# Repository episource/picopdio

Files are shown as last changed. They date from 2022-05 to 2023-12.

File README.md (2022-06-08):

# About
Another internet radio player project reusing parts and case of an old DNT IPdio Tune internet radio, that stopped working due to the shutdown of Reciva services.

The project is build using PlatformIO and [arduino-pico](https://github.com/earlephilhower/arduino-pico) core around a [Raspberry Pi Pico](https://www.raspberrypi.com/products/raspberry-pi-pico/) microcontroller. It uses nodejs' [llhttp](https://github.com/nodejs/llhttp) parser for reading icecast radio streams.

Configuration is stored on an SD card placed into the radio's front panel SD card slot.

# Parts
This is the list of parts used in the project. See the [schematics](schematics/picopdio.pdf) for details.

 * DNT IPdio Tune
    - Case
    - Mother board including Wolfson WM8711B audio codec/DAC and power supply
    - Front Panel including some unknown Tinsharp 132x48 LCD (ST7565 compatible)
 * [Raspberry Pi Pico](https://www.raspberrypi.com/products/raspberry-pi-pico/)
 * [Adafruit VS1053B Breakout](https://learn.adafruit.com/adafruit-vs1053-mp3-aac-ogg-midi-wav-play-and-record-codec-tutorial/downloads-and-links)
 * [Microchip MCP23017 IO Expander](https://www.microchip.com/en-us/product/mcp23017)
 * [Sparkfun SX1509 IO Expander](https://www.sparkfun.com/products/13601)
 * [WIZnet W850io SPI ethernet shield](https://www.wiznet.io/product-item/wiz850io/) ~~WIZnet W5500 based no-name `W5500 Lite` SPI ethernet adapter~~ 
   - no-name W850io clones had auto negotiation issues with some switches 
   - therefore replaced by WIZnet made W850io shield
   - note: disabling auto negotiation and forcing 100MBit or 10MBit Half Duplex instead solved these issues with the no-name clones as well
   - see also WIZnet forums for a [similar issue](https://forum.wiznet.io/t/topic/5529)
 * [Pololu Mini Pushbutton Power Switch #2808](https://www.pololu.com/product/2808)

# Further Reading
Below some links with background information on reciva based internet radios
 * [Sharpfin Webpage](https://www.sharpfin.org/)
 * [Sharpfin Repo](https://github.com/philsmd/sharpfin)
 * [Reciva Barracuda Radio Module Datasheet](https://elinux.org/images/5/5f/Barracuda_1.6.pdf)

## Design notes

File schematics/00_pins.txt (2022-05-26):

              G                 G 
  / 20 18 16 14 12 10 08 06 04 02 | J1
  | 19 17 15 13 11 09 07 05 03 01 |             J2/U11
       V3        G             V3               ------
     J3                                         02  01
     -----                                      04  03
     02 01 G                                    06  05
     04 03                                      08  07
     06 05                                      10  09 G
   G 08 07                                      12  11
     10 09                                   V3 14  13
     12 11                                    G 16  15
     14 13                                      18  17
     16 15                                      20  19
     18 17                                    G 22  21
     20 19  G                                   24  23 G
  NC 22 21 NC                                   26  25
  NC 24 23 NC                                 G 28  27
  NC 26 25 NC                                   30  29
  NC 28 27 NC                                   32  31 G
  NC 30 29 NC                                V3 34  33
  NC 32 31 NC                              V1.8 36  35
                                                38  37
                                              G 40  39

  / 01 02 03 04 05 06 07 08 09 10 11 12 13 14 15 16 |J7
  | 17 18 19 20 21 22 23 24 25 26 27 28 29 30 31 32 |

J1:
03 = SDDAT3 (CS) via J11/7 zu SD/10
05 = SDDAT2 via J11/8 zu SD/11
06 = WM8711B DACDAT (I2S DAT)
07 = SDDAT1 via J11/ zu SD/2
08 = WM8711B BCLK (I2S BCLK)
09 = SDDAT0 (MISO) via J11/ zu SD/3
10 = WM8711B DACLRC (I2S LRCLK)
13 = SDCMD (MOSI) via J11/6 zu SD/11
15 = SDCLK via Koaxkabel zu SD/05
16 = LCD Backlight FET via R60
19 = I2C SCL

J2:
01 = Power LED FET via R133
08 = I2C SDA
10 = SD Card Detect (SD/8) via J11/1
12 = SD Write Protect (SD/1) via J11/2
15 = Taster Drehknopf B | Taster Power Back
17 = Taster Pre/Play B | Taster Mode B | Taster Back B
19 = Drehgeber B
21 = Drehgeber A
33 = Drehknopf LED FET via R132

J3:
02 = Taster Drehknopf A | Taster Back A
04 = Taster Mode A | Taster Power A
06 = Taster Pre/Play A
----
03 = LCDD7
05 = LCDD6
07 = LCDD5
09 = LCDD4
11 = LCDD3
13 = LCDD2
15 = LCDD1
17 = LCDD0
----
10 = LCDN5/C5
12 = LCDN4/C4
14 = LCDN3/C3
16 = LCDN2/C2
18 = LCDN1/C1
20 = LCDN0/C0

Taster/Drehgeber: A = oben; B = unten

J7 -> Sockel/Pin = Beschreibung
1  -> J2/15      = Taster Drehknopf B | Taster Power B
3  -> J2/01      = Power LED FET via R133
4  -> J1/16      = LCD Backlight FET via R60 (Pulldown zu GND via R61)                                                                            
5                = GND
14  -> J2/17     = Taster Pre/Play B | Taster Mode B | Taster Back B
15  -> J2/19     = Drehgeber B
16               = GND
17  -> J3/04     = Taster Mode A | Taster Power A
20  -> J2/33     = Drehknopf LED FET via R132
21               = +5V
22               = +3V3?
29  -> J3/06     = Taster Pre/Play A
30  -> J3/02     = Taster Drehknopf A | Taster Back A
32  -> J2/21     = Drehgeber A

Drehgeber Mitte = GND, A/B per Kondensator zu Ground entprellt

Button-Matrix:

      | J3/02     | J3/04 | J3/06   
J2/15 | Drehknopf | Power | 
J2/17 | Back      | Mode  | Pre/Play

Notizen SD Card Socket

|  11 10 09 08 07 06 05 04 03 02 01
\___________________________________|

01 = Verbunden mit P07/P04 (GND) wenn Karte ohne Write Protect gesteckt oder keine Karte, high wenn WP -> J2/12
02 = SDDAT1 -> J1/7
03 = SDDAT0 -> J1/9
04 = GND
05 = SDCLK -> via Koaxkabel zu J1/15
06 = V3 (Kondensator zu GND)
07 = GND
08 = SD Card Detect (GND wenn Karte gesteckt) -> J2/10
09 = SDCMD -> J1/13
10 = SDDAT3 -> J1/3
11 = SDDAT2 -> J1/5

J11
|----|
| 01 | SD Card Detect (SD/08) -> J2/10
| 02 | SD Write Protect (SD/01) -> J2/12
| 03 | SDDAT1 -> J1/7
| 04 | SDDAT0 (MISO) -> J1/9
| 05 | seitlicher Pin SD Card Socket. Bedeutung unklar. Kondensator zu GND.
| 06 | SDCMD (MOSI) -> J1/13
| 07 | SDDAT3 (CS) -> J1/3
| 08 | SDDAT2 -> J1/5
| 09 | V3
| 10 | GND
|----|

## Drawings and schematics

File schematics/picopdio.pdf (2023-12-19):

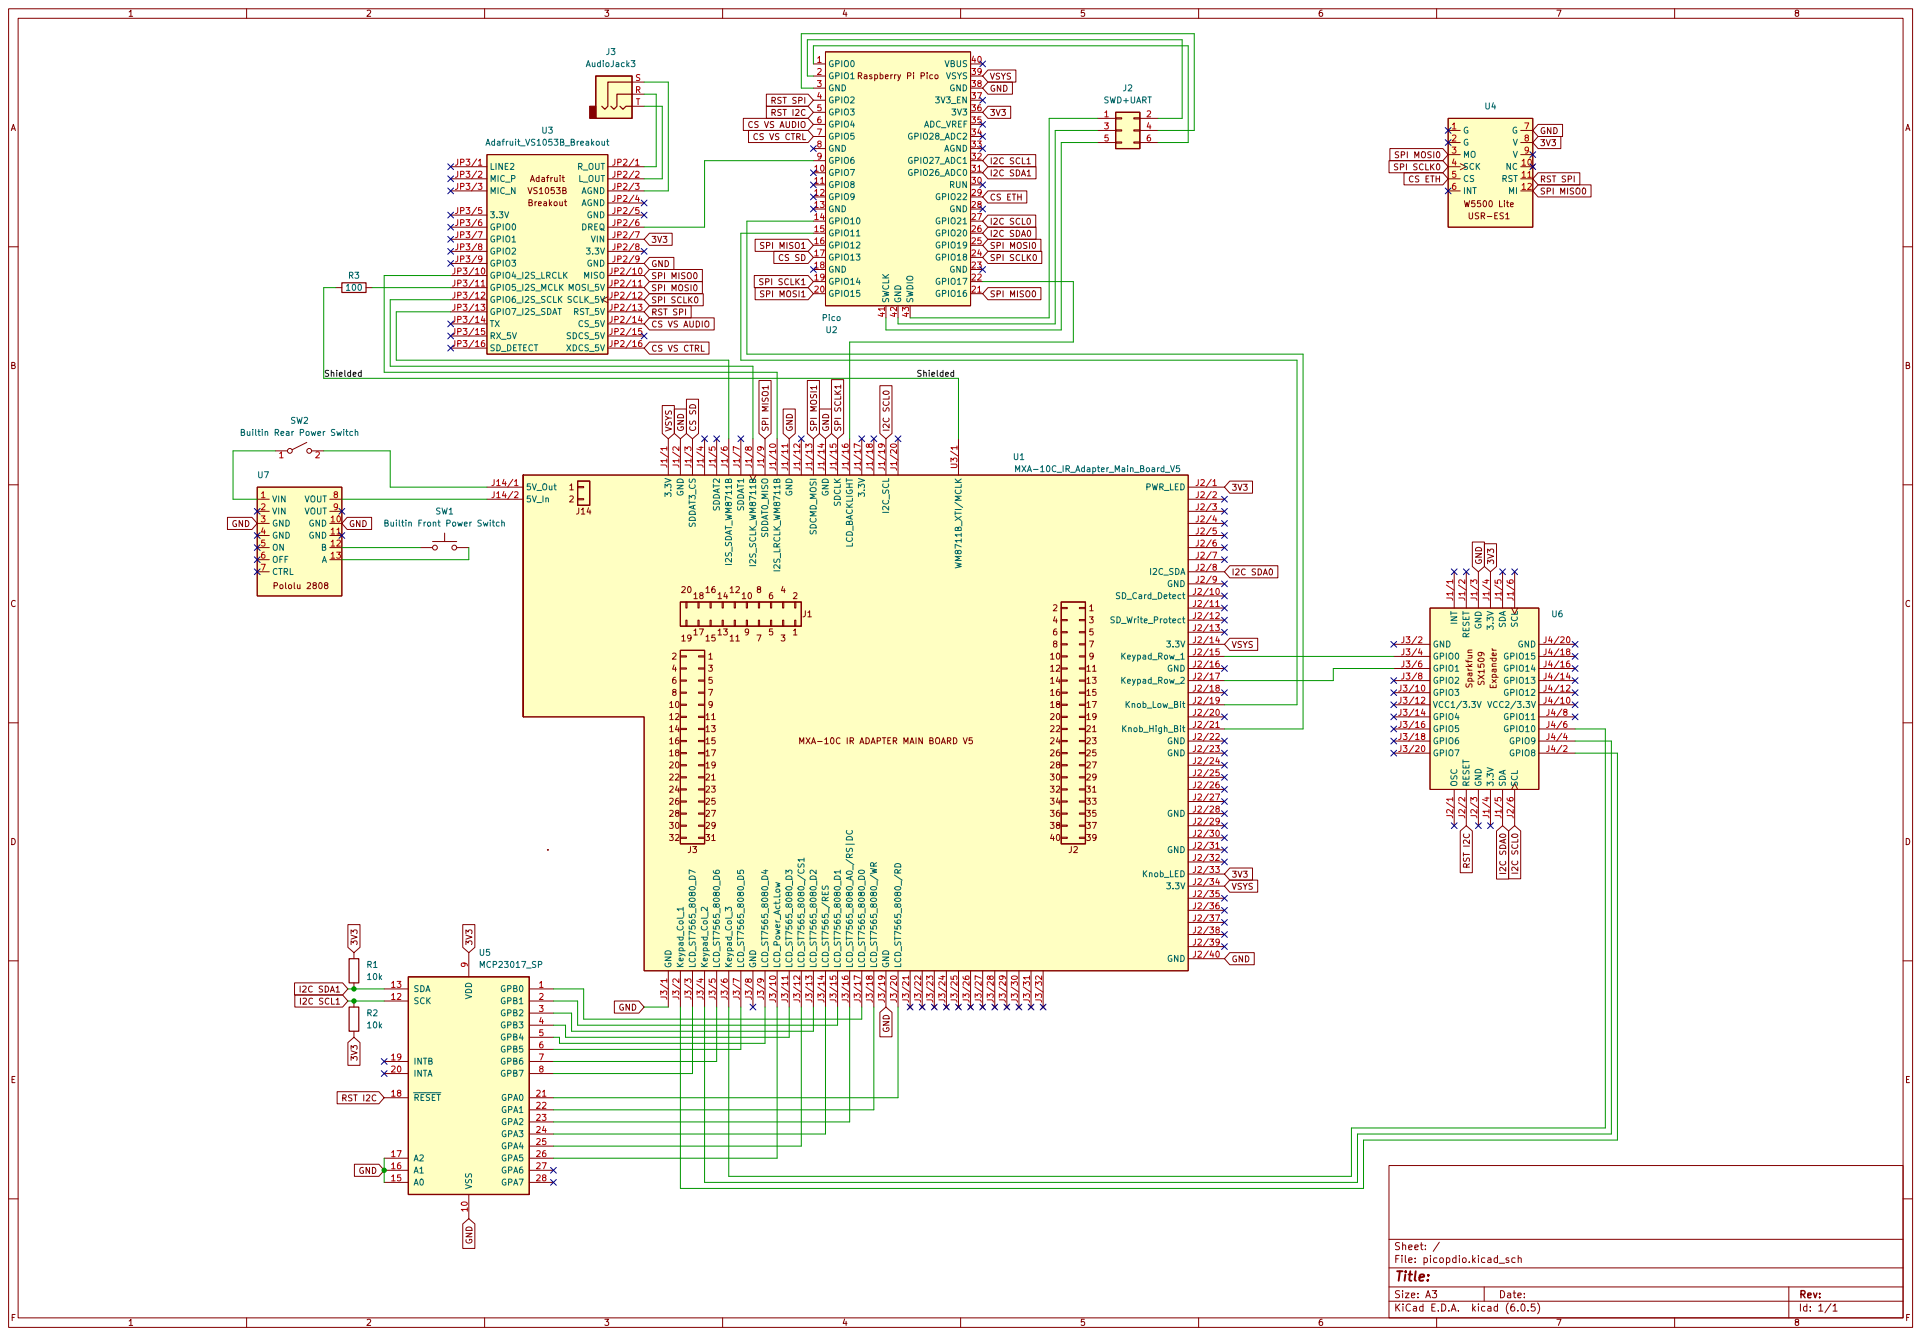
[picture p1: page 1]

SPI SCLK0 RST SPI GND GND

CS VS CTRL RST I2C

SPI SCLK1 SPI MISO1 CS SD

CS VS CTRL CS VS AUDIO

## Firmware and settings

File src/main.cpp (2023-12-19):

#include <Arduino.h>
#include <Ethernet3.h>
#include <pico.h>
#include <SdFat.h>
#include <SPI.h>
#include <Wire.h>

#include <RPi_Pico_TimerInterrupt.h>
#include <SparkFunSX1509.h>
#include <VS1053.h>

#include <hardware/watchdog.h>

#include "PicopdioDefinitions.h"

#include "PicopdioConfig.h"
#include "UserInterface.h"
#include "RotaryDecoder.h"
#include "IcyStreamClient.h"
#include "WM8711.h"


RPI_PICO_Timer khzHeartbeatTimer(0);
PicopdioConfig<10, 1000> picopdioConfig;
UserInterface ui(0x20, WIRE_HIGH_SPEED, 1, 1, 0, 4, 2, 3, 5);
RotaryDecoder rotdec;
EthernetClient ethClient;
VS1053 player(VS1053_CS, VS1053_DCS, VS1053_DREQ);
WM8711 dac(WIRE_LOW_SPEED, 0x1b);

// global variable required by IniFile library
SdFat SD;

// best buffer size: 8k - 32k
// feedLimit = 32000: EthernetClient shows nondeterministic behavior for larger sizes
IcyStreamClient<16000, 4096, 32000, false> icyStream(ethClient);

volatile uint8_t wantedStationIdx = 0;
critical_section_t wantedStationUpdateSection;

volatile bool core0SetupDone = false;
volatile bool playing = true;


SX1509 sx1509;

#define KEY_ROWS 2
#define KEY_COLS 3
#define KEY_UNUSED 0xff
#define KEY_DIM 0xfe
uint8_t keyMap[KEY_ROWS][KEY_COLS] = {
        {KEY_DIM, KEY_UNUSED, KEY_UNUSED},
        {2, 1, 0}
};

void setupOutLine(pin_size_t pin, PinStatus init);
void setupCsLine(pin_size_t pin);
void reboot();
void showHttpError(int statusCode);
void showNoLinkError();

uint8_t loadStation() {
    File32 stationFile = SD.open(STATION_FILE, FILE_READ);
    uint8_t result = stationFile.available() ? (uint8_t) stationFile.read() : 0;
    stationFile.close();

    if (result < 0) {
        return 0;
    } else if (result >= picopdioConfig.numStations()) {
        return picopdioConfig.numStations() - 1;
    }

    return result;
}

void storeStation(const uint8_t stationIdx) {
    const uint8_t curStationIdx = loadStation();
    if (stationIdx == curStationIdx) {
        DEBUGV("station file already up-to-date: %d - skipping write!\n", stationIdx);
        return;
    }

    File32 stationFile = SD.open(STATION_FILE, FILE_WRITE);
    stationFile.seek(0);
    stationFile.write(stationIdx);
    stationFile.close();

    DEBUGV("station file written: %d!\n", stationIdx);
}

bool khzHeartbeat(struct repeating_timer *t) {
    RotaryDecoder::Step step = rotdec.readAndDecode(CHANNEL_SELECTOR_ROT_HIGH, CHANNEL_SELECTOR_ROT_LOW);
    if (step == RotaryDecoder::NO_STEP) {
        return true;
    }

    critical_section_enter_blocking(&wantedStationUpdateSection);

    uint8_t maxStationIdx = picopdioConfig.numStations() - 1;
    if (step == RotaryDecoder::BACKWARD && wantedStationIdx == 0) {
        wantedStationIdx = maxStationIdx;
    } else if (step == RotaryDecoder::FORWARD && wantedStationIdx == maxStationIdx) {
        wantedStationIdx = 0;
    } else {
        wantedStationIdx += step;
    }

    critical_section_exit(&wantedStationUpdateSection);

    return true;
}

void setup() {
    critical_section_init(&wantedStationUpdateSection);

    //Serial.begin(115200);
    Serial1.begin(115200);

    SPI_MAIN.begin(false);
    SPI_DEDICATED_SD.begin(false);

    while (true) {
        DEBUGV("Initializing...\n");

        setupCsLine(ETH_CS);
        setupCsLine(SD_CS);
        setupCsLine(VS1053_CS);
        setupCsLine(VS1053_DCS);

        // configure reset line (no reset)
        delay(DEFAULT_INIT_DELAY_MS);
        setupOutLine(SPI_COMPONENTS_RESET_LOW, HIGH);

        if (!SD.begin(SdSpiConfig(SD_CS, DEDICATED_SPI, SPI_DEDICATED_SD_SPEED, &SPI_DEDICATED_SD))) {
            DEBUGV("Failed to init SD\n");
            continue;
        }

        if (!picopdioConfig.init(CONFIG_FILE)) {
            DEBUGV("Failed to read configuration from SD card!\n");
            continue;
        }

        if (picopdioConfig.numStations() == 0) {
            DEBUGV("No stations found!\n");
            continue;
        }

        // no need to enter critical section here:
        // parallelism starts when core0 is ready
        wantedStationIdx = loadStation();


        // Reset other spi slaves
        digitalWrite(SPI_COMPONENTS_RESET_LOW, LOW);
        delay(DEFAULT_INIT_DELAY_MS);
        digitalWrite(SPI_COMPONENTS_RESET_LOW, HIGH);

        delay(DEFAULT_INIT_DELAY_MS);
        Ethernet.setCsPin(ETH_CS);
        Ethernet.init(2);
        Ethernet.begin(
                const_cast<uint8_t *>(picopdioConfig.getMac()),
                picopdioConfig.getIp(), picopdioConfig.getDns(), picopdioConfig.getGateway());

        switch (picopdioConfig.compatMode()) {
            case ETH_FULL_AUTONEG:
                Ethernet.phyMode(ALL_AUTONEG);
                break;
            case ETH_100_HD:
                Ethernet.phyMode(HALF_DUPLEX_100);
                break;
            case ETH_10_HD:
                Ethernet.phyMode(HALF_DUPLEX_10);
                break;
            case ETH_HW_DEFAULT:
            default:
                // nothing to do
                break;
        }


        player.begin();

        // 4 == VS1053;
        if (player.getChipVersion() != 4) {
            DEBUGV("Unknown VLSI chip %d\n");
            continue;
        }
        player.loadDefaultVs1053Patches();

        //player.switchToMp3Mode(); // optional, some boards require this
        player.setVolume(0);
        player.enableI2sOut();

        break;
    }

    icyStream.setOnIcyMetadataChanged([]() -> void {
        if (playing) {
            ui.setTitle(icyStream.icyTitle());
        }
    });

    core0SetupDone = true;
}

void loop() {
    static uint8_t connectedStationIdx = UINT8_MAX;
    static int minBuffer = 100;
    static uint8_t bufLevel = 4;
    static uint32_t lastBufLevelUpdateMillis = 0;
    static bool lastLinkState = true;

    uint8_t requestedStationIdx = wantedStationIdx;
    uint32_t nowMs = millis();
    boolean stationChangeRequested = requestedStationIdx != connectedStationIdx;

    if (!icyStream.connected() || (bool)Ethernet.link() != lastLinkState || stationChangeRequested) {
        if (playing) {
            player.setVolume(0);
            player.stopSong();

            playing = false;
        }

        if (!Ethernet.link()) {
            if (lastLinkState) {
                icyStream.stop();
                showNoLinkError();
            }

            lastLinkState = false;
            return;
        }

        if (stationChangeRequested || !lastLinkState) {
            DEBUGV("Link ready - PHY state: 0x%02x\n", Ethernet.phyState());

            ui.showLoadScreen();

            icyStream.connect(picopdioConfig.getStationUrl(requestedStationIdx));
            connectedStationIdx = requestedStationIdx;

            lastLinkState = true;
        } else {
            return;
        }
    } else if (nowMs - lastBufLevelUpdateMillis > 1000) {
        lastBufLevelUpdateMillis = nowMs;

        if (minBuffer > 80 || icyStream.bufferFull()) {
            bufLevel = 4;
        } else if (minBuffer > 55) {
            bufLevel = 3;
        } else if (minBuffer > 30) {
            bufLevel = 2;
        } else if (minBuffer > 5) {
            bufLevel = 1;
        } else {
            bufLevel = 0;
        }

        minBuffer = 100;
        ui.setBufferLevel(bufLevel);
    }

    const int read = icyStream.feedBuffer();
    if (read < 0) {
        showHttpError(icyStream.httpStatus());
        icyStream.stop();
    }

    minBuffer = std::min(minBuffer, icyStream.bufferFillPercent());

    if (!playing) {
        if (!icyStream.bufferFull()) {
            return;
        }

        player.startSong();
        player.setVolume(VOLUME);
        playing = true;

        lastBufLevelUpdateMillis = nowMs;
        minBuffer = 100;
        bufLevel = 4;

        ui.showTitleScreen(icyStream.icyTitle(), 4);
        storeStation(connectedStationIdx);
    }

    icyStream.readTo([](const uint8_t *data, int size) -> int {
        return player.playNonBlocking(data, size);
    });
}

void setup1() {
    // activate LCD backlight as early as possible to provide user feedback
    pinMode(LCD_BG, ANALOG_OUTPUT);
    analogWrite(LCD_BG, LCD_DEFAULT_BRIGHTNESS);

    // reset I2C slaves
    setupOutLine(I2C_COMPONENTS_RESET_LOW, LOW);
    delay(DEFAULT_INIT_DELAY_MS);
    digitalWrite(I2C_COMPONENTS_RESET_LOW, HIGH);

    pinMode(CHANNEL_SELECTOR_ROT_HIGH, INPUT_PULLUP);
    pinMode(CHANNEL_SELECTOR_ROT_LOW, INPUT_PULLUP);

    WIRE_LOW_SPEED.setSCL(WIRE_LOW_SPEED_SCL);
    WIRE_LOW_SPEED.setSDA(WIRE_LOW_SPEED_SDA);
    WIRE_LOW_SPEED.setClock(400000);
    WIRE_LOW_SPEED.begin();

    WIRE_HIGH_SPEED.setSCL(WIRE_HIGH_SPEED_SCL);
    WIRE_HIGH_SPEED.setSDA(WIRE_HIGH_SPEED_SDA);
    // rp2040 is specified to support Fast Mode+ (up to 1MHz Baud Rate)
    // it has 80k builtin internal pull-ups
    // MCP23017 is specified to support baud rate up to 1.7MHz
    // - using external pull-ups rp2040 can do more than 1MHz, though
    // - using external 10k pull-ups, 1.35MHz baud rate seem to work most
    //   of the time, up to 1.30MHZ stable,
    // - using lower pull-ups does not help to achieve higher rate
    // - note though, that going >1MHZ makes the bus very sensitive to noise
    //   on breadboard designs
    WIRE_HIGH_SPEED.setClock(1300000);
    WIRE_HIGH_SPEED.begin();

    // early display of gui!
    ui.begin(true);
    if (ui.resetRequest()) {
        DEBUGV("Failed to initialize display. Rebooting...\n");
        reboot();
    }

    // start dac + shaft and key decoding only after core 0 is ready
    // => stations not available before SD card has been read
    // => MCLK not ready
    while (!core0SetupDone) {
        yield();
    }

    // wait for core0 for MCLK to be ready
    dac.begin();

    // wait for core0 to finish reading PicopdioConfig
    khzHeartbeatTimer.attachInterrupt(1000, khzHeartbeat);

    sx1509.begin(0x3E, WIRE_LOW_SPEED);
    sx1509.reset(false);

    // normal buttons: debounce time 4ms is good
    // rotary switch button: debounce time must be >= 16ms!
    sx1509.keypad(KEY_ROWS, KEY_COLS, 0, 32, 16);

    DEBUGV("Core1 ready!\n");
}

void loop1() {
    if (ui.resetRequest()) {
        DEBUGV("Resetting display...\n");
        ui.begin(false);
    }

    uint32_t now = millis();

    uint16_t keyData = 0;
    static uint32_t lastSx1509KeydataMs = 0;
    if (now - lastSx1509KeydataMs > 100) {
        lastSx1509KeydataMs = now;
        keyData = sx1509.readKeyData();
    }
    if (keyData != 0) {
        uint8_t row = sx1509.getRow(keyData);
        uint8_t col = sx1509.getCol(keyData);

        if (row < KEY_ROWS && col < KEY_COLS) {
            uint8_t key = keyMap[row][col];
            if (key == KEY_DIM) {
                constexpr uint8_t brightnessIncrement = (LCD_MAX_BRIGHTNESS - LCD_MIN_BRIGHTNESS) / LCD_BRIGHTNESS_STEPS;
                static uint8_t lcdBrightness = LCD_DEFAULT_BRIGHTNESS;

                if (lcdBrightness == LCD_MIN_BRIGHTNESS) {
                    lcdBrightness = LCD_MAX_BRIGHTNESS;
                } else {
                    lcdBrightness -= std::min(brightnessIncrement, lcdBrightness);

                    if (lcdBrightness < LCD_MIN_BRIGHTNESS) {
                        lcdBrightness = LCD_MAX_BRIGHTNESS;
                    }
                }

                analogWrite(LCD_BG, lcdBrightness);
            } else if (key != KEY_UNUSED) {
                critical_section_enter_blocking(&wantedStationUpdateSection);
                wantedStationIdx = key;
                critical_section_exit(&wantedStationUpdateSection);
            }
        }
    }

    static bool muted = false;
    if (muted == playing) {
        muted = !playing;
        if (muted) {
            dac.mute();
            dac.setHeadphoneVolume(0);
        } else {
            dac.setHeadphoneVolume(VOLUME);
            dac.unmute();
        }
    }

    uint8_t requestedStationIdx = wantedStationIdx;
    static uint8_t currentDisplayStationIdx = UINT8_MAX;
    if (requestedStationIdx != currentDisplayStationIdx) {
        ui.showLoadScreen(requestedStationIdx + 1, picopdioConfig.getStationName(requestedStationIdx).raw());
        currentDisplayStationIdx = requestedStationIdx;
    }

    ui.loop();
}

void setupOutLine(pin_size_t pin, PinStatus init) {
    pinMode(pin, OUTPUT);
    digitalWrite(pin, init);
}

void setupCsLine(pin_size_t pin) {
    setupOutLine(pin, HIGH);
}

void reboot() {
    watchdog_reboot(0, 0, 10);
    while (true) {
        yield();
    }
}

void showHttpError(int statusCode) {
    if (statusCode != 0) {
        constexpr int maxLen = 30;
        char msgBuffer[maxLen];
        snprintf(msgBuffer, maxLen, "Keine Verbindung. HTTP %d.", icyStream.httpStatus());
        ui.showTitleScreen(msgBuffer, 0);
    } else {
        ui.showTitleScreen("Keine Verbindung.", 0);
    }
}
void showNoLinkError() {
    ui.showTitleScreen("Kein Netzwerk.", 0);
}

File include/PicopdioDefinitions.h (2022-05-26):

#pragma once

#define SPI_COMPONENTS_RESET_LOW 2
#define I2C_COMPONENTS_RESET_LOW 3

#define ETH_CS 22

#define SD_CS 13

#define VS1053_CS 4
#define VS1053_DCS 5
#define VS1053_DREQ 6

#define LCD_BG 17

#define WIRE_HIGH_SPEED_SCL PIN_WIRE1_SCL
#define WIRE_HIGH_SPEED_SDA PIN_WIRE1_SDA
#define WIRE_LOW_SPEED_SCL 21
#define WIRE_LOW_SPEED_SDA 20

#define CHANNEL_SELECTOR_ROT_HIGH 10
#define CHANNEL_SELECTOR_ROT_LOW 11

#define DEFAULT_INIT_DELAY_MS 100

#define VOLUME  80 // volume level 0-100

#define CONFIG_FILE "picopdio.ini"
#define STATION_FILE "station.idx"

#define WIRE_LOW_SPEED Wire
#define WIRE_HIGH_SPEED Wire1

#define SPI_MAIN SPI
#define SPI_DEDICATED_SD SPI1
#define SPI_DEDICATED_SD_SPEED SPI_DIV3_SPEED

#define LCD_BRIGHTNESS_STEPS 4
#define LCD_MIN_BRIGHTNESS 16
#define LCD_MAX_BRIGHTNESS 128
#define LCD_DEFAULT_BRIGHTNESS LCD_MAX_BRIGHTNESS // should be near to 125 for best view

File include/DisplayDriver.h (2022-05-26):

#pragma once

#include <Arduino.h>
#include <U8g2lib.h>

#ifndef U8X8_WITH_USER_PTR
#error Not defined: U8X8_WITH_USER_PTR
#endif

class DisplayGpioAdapter {
public:
    virtual void begin();
    virtual void pinMode(pin_size_t pinNumber, PinMode pinMode);
    virtual void digitalWrite(pin_size_t pinNumber, PinStatus status);
    virtual PinStatus digitalRead(pin_size_t pinNumber);
    virtual void writeBank(pin_size_t bankNumber, uint8_t status);
    virtual void setBankMode(pin_size_t bankNumber, PinMode pinMode);
    virtual uint8_t readBank(pin_size_t bankNumber);
};
inline DisplayGpioAdapter DefaultGpioAdapter;

// bufrows:
// - 0 means full buffer (u8g2 conventional suffix _f)
// - 1 means buffer of one page/row (u8g2 conventional suffix _1)
// - 2 means buffer of two pages/rows (u8g2 conventional suffix _2)
template<int bufrows = 1>
class U8G2_ST7565_KS0713_132x48_8080 : public U8G2 {
public:
    U8G2_ST7565_KS0713_132x48_8080(const u8g2_cb_t *rotation, uint8_t dataBank, uint8_t wr_enable, uint8_t rd,
                                   uint8_t cs, uint8_t dc, uint8_t reset, uint8_t power,
                                   DisplayGpioAdapter &displayGpio)
            : U8G2_ST7565_KS0713_132x48_8080(rotation, dataBank, U8X8_PIN_NONE, U8X8_PIN_NONE, U8X8_PIN_NONE,
                                             U8X8_PIN_NONE, U8X8_PIN_NONE, U8X8_PIN_NONE, U8X8_PIN_NONE, U8X8_PIN_NONE,
                                             wr_enable, rd, cs, dc, reset, power, displayGpio) {
    }

    U8G2_ST7565_KS0713_132x48_8080(const u8g2_cb_t *rotation, uint8_t d0, uint8_t d1, uint8_t d2, uint8_t d3,
                                   uint8_t d4, uint8_t d5, uint8_t d6, uint8_t d7, uint8_t wr_enable, uint8_t rd,
                                   uint8_t cs, uint8_t dc, uint8_t reset, uint8_t power,
                                   DisplayGpioAdapter &displayGpio = DefaultGpioAdapter)
            : U8G2_ST7565_KS0713_132x48_8080(rotation, U8X8_PIN_NONE, d0, d1, d2, d3, d4, d5, d6, d7, wr_enable, rd, cs,
                                             dc, reset, power, displayGpio) {
    }

protected:
    U8G2_ST7565_KS0713_132x48_8080(const u8g2_cb_t *rotation, uint8_t dataBank, uint8_t d0, uint8_t d1, uint8_t d2, uint8_t d3,
                                   uint8_t d4, uint8_t d5, uint8_t d6, uint8_t d7, uint8_t wr_enable, uint8_t rd,
                                   uint8_t cs, uint8_t dc, uint8_t reset, uint8_t power,
                                   DisplayGpioAdapter &displayGpio)
            : gpio(displayGpio), powerPin(power), rdPin(rd), dataBank(dataBank) {
        getU8x8()->user_ptr = this;
        u8g2_Setup_ST7565_KS0713_132x48(&u8g2, rotation, byte_cb, gpio_and_delay_cb);
        u8x8_SetPin_8Bit_8080(getU8x8(), d0, d1, d2, d3, d4, d5, d6, d7, wr_enable, cs, dc, reset);
    }

private:
    void u8g2_Setup_ST7565_KS0713_132x48(u8g2_t *u8g2, const u8g2_cb_t *rotation, u8x8_msg_cb byte_cb,
                                         u8x8_msg_cb gpio_and_delay_cb) {
        u8g2_SetupDisplay(u8g2, u8x8_d_ST7565_KS0713_132x48, u8x8_cad_001, byte_cb, gpio_and_delay_cb);
        u8g2_SetupBuffer(u8g2, tileBuf, tileBufHeightInTiles, u8g2_ll_hvline_vertical_top_lsb, rotation);
    }

    static uint8_t u8x8_d_ST7565_KS0713_132x48(u8x8_t *u8x8, uint8_t msg, uint8_t arg_int, void *arg_ptr) {
        if (msg == U8X8_MSG_DISPLAY_SETUP_MEMORY) {
            u8x8_d_helper_display_setup_memory(u8x8, &u8x8_ST7565_KS0713_132x48_display_info);
            return true;
        }
        if (msg == U8X8_MSG_DISPLAY_INIT) {
            const U8G2_ST7565_KS0713_132x48_8080<bufrows> *self = (U8G2_ST7565_KS0713_132x48_8080<bufrows> *) u8x8->user_ptr;

            if (self->rdPin != U8X8_PIN_NONE) {
                self->gpio.digitalWrite(self->rdPin, PinStatus::LOW); // active high; never read => LOW
            }

            if (self->powerPin != U8X8_PIN_NONE) {
                self->gpio.digitalWrite(self->powerPin, PinStatus::LOW); // active low
            }

            u8x8_d_helper_display_init(u8x8);
            u8x8_cad_SendSequence(u8x8, u8x8_d_ST7565_KS0713_132x48_init_seq);
            return true;
        }

        return u8x8_d_st7565_lm6059(u8x8, msg, arg_int, arg_ptr);
    }

    static uint8_t byte_cb(u8x8_t *u8x8, uint8_t msg, uint8_t arg_int, void *arg_ptr) {
        const U8G2_ST7565_KS0713_132x48_8080<bufrows> *self = (U8G2_ST7565_KS0713_132x48_8080<bufrows> *) u8x8->user_ptr;

        if (msg == U8X8_MSG_BYTE_SEND && self->dataBank != U8X8_PIN_NONE) {
            uint8_t *data = (uint8_t *) arg_ptr;
            while (arg_int > 0) {
                self->gpio.writeBank(self->dataBank, *data);
                data++;
                arg_int--;

                u8x8_gpio_Delay(u8x8, U8X8_MSG_DELAY_NANO, u8x8->display_info->data_setup_time_ns);
                u8x8_gpio_call(u8x8, U8X8_MSG_GPIO_E, 0);
                u8x8_gpio_Delay(u8x8, U8X8_MSG_DELAY_NANO, u8x8->display_info->write_pulse_width_ns);
                u8x8_gpio_call(u8x8, U8X8_MSG_GPIO_E, 1);
            }

            return true;
        }

        return u8x8_byte_arduino_8bit_8080mode(u8x8, msg, arg_int, arg_ptr);
    }

    static uint8_t gpio_and_delay_cb(u8x8_t *u8x8, uint8_t msg, uint8_t arg_int, void *arg_ptr) {
        U8G2_ST7565_KS0713_132x48_8080<bufrows> *self = (U8G2_ST7565_KS0713_132x48_8080<bufrows> *) u8x8->user_ptr;
        uint8_t i;
        switch (msg) {
            case U8X8_MSG_GPIO_AND_DELAY_INIT:

                if (self->dataBank != U8X8_PIN_NONE) {
                    self->gpio.setBankMode(self->dataBank, PinMode::OUTPUT);
                }

                if (self->rdPin != U8X8_PIN_NONE) {
                    self->gpio.pinMode(self->rdPin, PinMode::OUTPUT);
                }

                if (self->powerPin != U8X8_PIN_NONE) {
                    self->gpio.pinMode(self->powerPin, PinMode::OUTPUT);
                }

                for (i = 0; i < U8X8_PIN_CNT; i++)
                    if (u8x8->pins[i] != U8X8_PIN_NONE) {
                        if (i < U8X8_PIN_OUTPUT_CNT) {
                            self->gpio.pinMode(u8x8->pins[i], PinMode::OUTPUT);
                        } else {
#ifdef INPUT_PULLUP
                            self->gpio.pinMode(u8x8->pins[i], PinMode::INPUT_PULLUP);
#else
                            self->gpio.pinMode(u8x8->pins[i], PinMode::OUTPUT);
                            self->gpio.digitalWrite(u8x8->pins[i], PinStatus::HIGH);
#endif
                        }
                    }

                break;
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

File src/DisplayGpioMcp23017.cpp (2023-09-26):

#include "DisplayGpioMcp23017.h"

PlatformAndSharedMCP23017Gpio::PlatformAndSharedMCP23017Gpio(MCP23017 &mcp23017) : mcp23017(mcp23017){

}

void PlatformAndSharedMCP23017Gpio::pinMode(pin_size_t pinNumber, PinMode pinMode) {
    pin_size_t internalPinNumber = pinNumber;
    if (translatePin(pinNumber, internalPinNumber)) {
        mcp23017.pinMode(internalPinNumber, pinMode);
        DEBUGMCP_ERR(mcp23017, "MCP23017 pinMode failed: 0x%x\n");
    } else {
        DisplayGpioAdapter::pinMode(pinNumber, pinMode);
    }
}

void PlatformAndSharedMCP23017Gpio::digitalWrite(pin_size_t pinNumber, PinStatus status) {
    pin_size_t internalPinNumber = pinNumber;
    if (translatePin(pinNumber, internalPinNumber)) {
        mcp23017.digitalWrite(internalPinNumber, status);
        DEBUGMCP_ERR(mcp23017, "MCP23017 digitalWrite failed: 0x%x\n");
    } else {
        DisplayGpioAdapter::digitalWrite(pinNumber, status);
    }
}

PinStatus PlatformAndSharedMCP23017Gpio::digitalRead(pin_size_t pinNumber) {
    pin_size_t internalPinNumber = pinNumber;
    if (translatePin(pinNumber, internalPinNumber)) {
        PinStatus result = (PinStatus)mcp23017.digitalRead(internalPinNumber);
        DEBUGMCP_ERR(mcp23017, "MCP23017 digitalRead failed: 0x%x\n");
        return result;
    }
    return DisplayGpioAdapter::digitalRead(pinNumber);
}

void PlatformAndSharedMCP23017Gpio::writeBank(pin_size_t bankNumber, uint8_t status) {
    pin_size_t internalBankNumber = bankNumber;
    if (translatePin(bankNumber, internalBankNumber)) {
        mcp23017.write8(internalBankNumber, status);
        DEBUGMCP_ERR(mcp23017, "MCP23017 write8 failed: 0x%x\n");
    }
    DisplayGpioAdapter::writeBank(bankNumber, status);
}

void PlatformAndSharedMCP23017Gpio::setBankMode(pin_size_t bankNumber, PinMode pinMode) {
    pin_size_t internalBankNumber = bankNumber;
    if (translatePin(bankNumber, internalBankNumber)) {
        mcp23017.pinMode8(internalBankNumber, pinMode == OUTPUT ? 0 : 1);
        DEBUGMCP_ERR(mcp23017, "MCP23017 pinMode8 failed: 0x%x\n");
        mcp23017.setPullup8(internalBankNumber, pinMode == INPUT_PULLUP ? 1 : 0);
        DEBUGMCP_ERR(mcp23017, "MCP23017 setPullup8 failed: 0x%x\n");
    }
    DisplayGpioAdapter::setBankMode(bankNumber, pinMode);
}

uint8_t PlatformAndSharedMCP23017Gpio::readBank(pin_size_t bankNumber) {
    pin_size_t internalBankNumber = bankNumber;
    if (translatePin(bankNumber, internalBankNumber)) {
        uint8_t result = mcp23017.read8(internalBankNumber);
        DEBUGMCP_ERR(mcp23017, "MCP23017 read8 failed: 0x%x\n");
        return result;
    }
    return DisplayGpioAdapter::readBank(bankNumber);
}

bool PlatformAndSharedMCP23017Gpio::translatePin(pin_size_t externalPinNumber, pin_size_t &internalPinNumber) const {
    if (externalPinNumber >= mcpGpioOffset) {
        internalPinNumber = externalPinNumber - mcpGpioOffset;
        return true;
    }

    internalPinNumber = externalPinNumber;
    return false;
}


ExclusiveMCP23017Gpio::ExclusiveMCP23017Gpio(int mcp23017Addr, TwoWire *i2c)
    : mcp23017(mcp23017Addr, i2c) {
}

void ExclusiveMCP23017Gpio::begin() {
    for(int i = 0; !mcp23017.begin(); ++i) {
        DEBUGMCP_ERR(mcp23017, "MCP23017 begin failed: 0x%x\n");
        delay(10);

        if (i > 10) {
            DEBUGV("MCP23017 persistent communication error - rebooting!");
            reset_request = true;
            return;
        }
    }

    reset_request = false;
}

void ExclusiveMCP23017Gpio::pinMode(pin_size_t pinNumber, PinMode pinMode) {
    mcp23017.pinMode(pinNumber, pinMode);
    HANDLEMCP_ERR(mcp23017, "MCP23017 pinMode failed: 0x%x\n");
}

void ExclusiveMCP23017Gpio::digitalWrite(pin_size_t pinNumber, PinStatus status) {
    mcp23017.digitalWrite(pinNumber, status);
    HANDLEMCP_ERR(mcp23017, "MCP23017 digitalWrite failed: 0x%x\n");
}

PinStatus ExclusiveMCP23017Gpio::digitalRead(pin_size_t pinNumber) {
    pin_size_t bankNumber = pinNumber < 8 ? 0 : 1;
    uint8_t pBit = pinNumber < 8 ? pinNumber : pinNumber - 8;
    uint8_t status = readBank(bankNumber);

    return (PinStatus)((status >> pBit) & 0x1);
}

void ExclusiveMCP23017Gpio::writeBank(pin_size_t bankNumber, uint8_t status) {
    if (bankNumber > MAX_BANK) {
        DEBUGMCP("writeBank failed - illegal bank number: %d\n", bankNumber);
    }

    uint8_t curStatus = gpioState[bankNumber];

    if (curStatus != status) {
        mcp23017.write8(bankNumber, status);
        HANDLEMCP_ERR(mcp23017, "MCP23017 write8 failed: 0x%x\n");

        if (mcp23017.lastError() == MCP23017_OK) {
            gpioState[bankNumber] = status;
        }
    }
}

void ExclusiveMCP23017Gpio::setBankMode(pin_size_t bankNumber, PinMode pinMode) {
    mcp23017.pinMode8(bankNumber, pinMode == OUTPUT ? 0 : 1);
    HANDLEMCP_ERR(mcp23017, "MCP23017 pinMode8 failed: 0x%x\n");
    mcp23017.setPullup8(bankNumber, pinMode == INPUT_PULLUP ? 1 : 0);
    HANDLEMCP_ERR(mcp23017, "MCP23017 setPullup8 failed: 0x%x\n");
}
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

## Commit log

2022-05-26 Merge branch 'feature/start' into 'main'
    Initial version
    See merge request episource/picopdio!1
    [picopdio.kicad_sch]
2022-05-30 Add option to disable ethernet autonegotiation
    ... china made W5500 shields seem to have incompatibilities with some switches regarding autonegotiation. These can be circumvented by forcing a specific link mode. Only half uplex options are made available, as this is the only way to go if the other side (switch) should continue to use autonegotiation: parallel detection fallback mechanism is not able to detect duplex mode.
2022-05-30 Fix station change overflow handling
    [main.cpp]
2023-01-14 Reduce i2c speed to nominal max
    Max i2c speed is specified as 1MHz for pico. Previous speed was higher and
    seemed to work at the beginning, but was not 100% reliable in the end.
2023-09-19 Fix handling of urls with port
    [IcyStreamClient.h]
2023-09-22 Force arduino-pico framework v1.13.0 for reliable build
2023-09-26 Reset display on i2c comms error
    [DisplayGpioMcp23017.cpp, DisplayGpioMcp23017.h, UserInterface.h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]
2023-09-28 Use maxgerhardt's arduino-pico platform
2023-12-17 Reset if feedBuffer has no data ready for too long
    [main.cpp]
2023-12-18 Show link and http errors on display
    [IcyStreamClient.h, main.cpp]
2023-12-19 Improve power supply
    [picopdio.kicad_sch]
2023-12-19 Increase clocks after improving power supply
2024-03-31 Fix string literal to char* conversion
    [UserInterface.h]
